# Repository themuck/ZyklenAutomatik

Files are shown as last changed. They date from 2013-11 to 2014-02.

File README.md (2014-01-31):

ZyklenAutomatik
==========
Elektronisches Getriebe mit Zyklen Funktion auf auf Arduino Mega2560 Basis. Zur Nachbildung eines Getriebes für die Leitspindel einer Drehbank

<br />Dieses Werk bzw. Inhalt ist lizenziert unter einer <a rel="license" href="http://creativecommons.org/licenses/by-nc-sa/3.0/deed.de">Creative Commons Namensnennung - Nicht-kommerziell - Weitergabe unter gleichen Bedingungen 3.0 Unported Lizenz</a>.

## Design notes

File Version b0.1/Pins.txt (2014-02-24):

Pins - Funktion RJ45 (Encoder A,A' / B, B' / Z,Z')
8- GND 	BR
7- 5V	BR/W
6- B+	GR
5- Z-	BL/w
4- Z+	BL
3- B-	GR/W
2- A- 	OR
1- A+	OR/W
---------------
Pins - Funktion RJ45 (Encoder A/B/Z und Eingänge (Endschalter) )
8- GND
7- 5V
6- B+
5- Arduino 41
4- Z+
3- Arduino 39
2- Arduino 38
1- A+
--------------
Pins - Funktion RJ45 (Endstufe)
8- GND
7- Arduino 11 (Status Eingang)
6- 5V
5- Arduino 8 Dir Pin
4- 5V
3- Arduino 9 Step Pin
2- GND
1- Arduino 10 Enable

----------------
S1- Arduino 42
S2- Arduino 43
S3- Arduino 44
S4- Arduino 45
S5- Arduino 46
S6- Arduino 47
S7- Arduino 48
S8- Arduino 49
S9- Arduino 50 
S10- Adruino 51
S11- Arduino 40 (Encoder Taster)
S12 - Reset

Encoder A- Arduino 19 Int4
Encoder B- Arduino 20 Int3

Externer Encoder A- Arduino 2 Int0
Externer Encoder B- Arduino 3 Int1

Endschalter - 38
Endschalter - 39
Endschalter - 41

LED Status 1- Arduino 53
LED Status 2- Arduino 52
LED Status 3- Arduino 30
LED Status 4- Arduino 31
Summer- Arduino 32

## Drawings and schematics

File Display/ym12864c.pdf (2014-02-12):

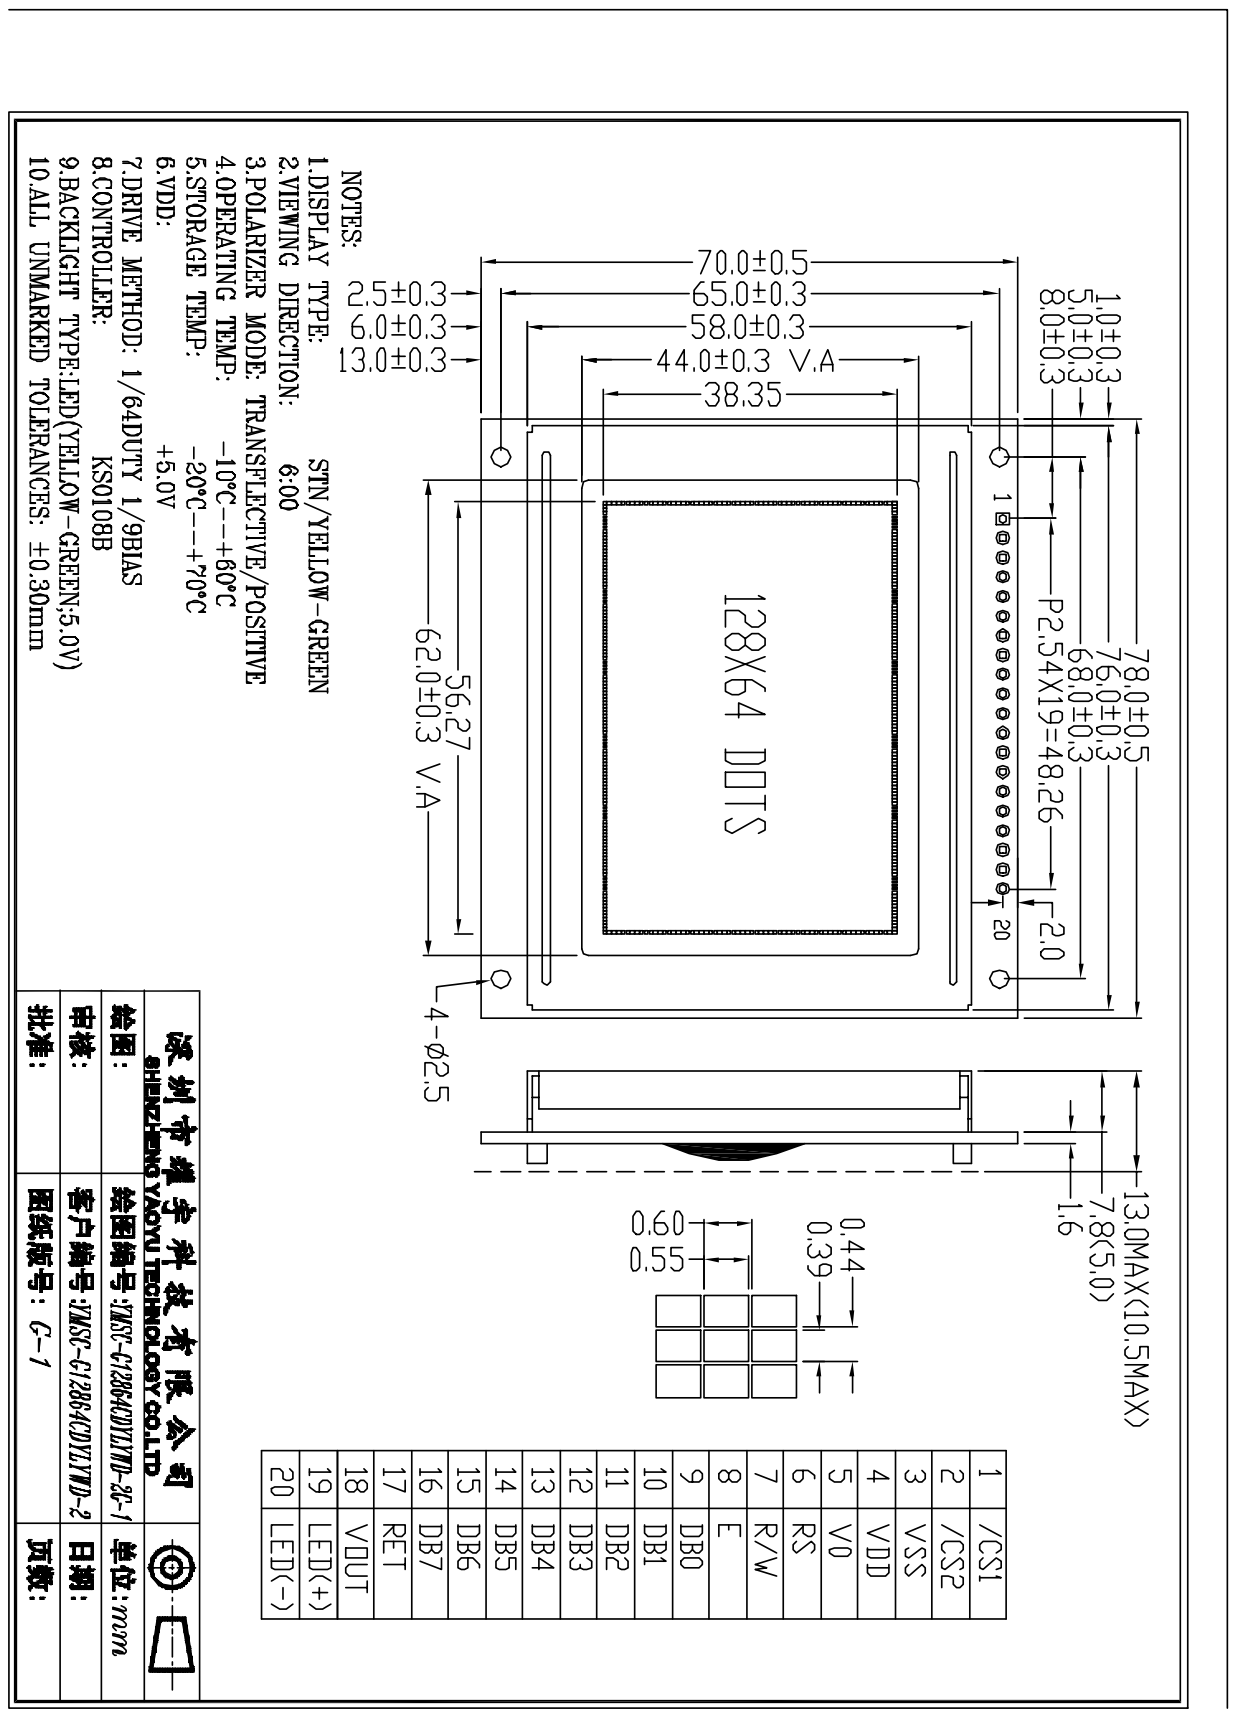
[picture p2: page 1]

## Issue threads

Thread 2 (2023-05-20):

Problem

beyma1, 2023-05-20:
Czy kod jest kompletny? Zbudowałem projekt, wgrałem soft do arduino ale nie ma żadnej reakcji na impulsator. Tak samo nie ma "tej kreseczki"? co przesuwa się gdy zmienia się tryb na wyświetlaczu. Co może być przyczyną?

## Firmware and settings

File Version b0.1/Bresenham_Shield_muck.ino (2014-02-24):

// use AVR446 - Linear speed control of stepper motor Documentation, Atmel AVR Application Note
// ZykloenAutomatik is Open Source under CC BY-NC-SA 3.0 
// https://github.com/themuck/ZyklenAutomatik

/* TO DO 
- Aufräumen
- Kommentare
- delay(); Funktion entfernen
- Shönere Struktur, If anweisungen - > switch / case 
- Programm Verriegelungen 
- Entprellroutine ?
- Winkel Positions Anzege
- Visualisierung LEDs, Töne 
- Variablen größe
- Bresenham rirchtung
- Zahlenwerte Negativ verriegeln 
-....
*/

#include <glcd.h>
#include "ZyklenAutomatik_Config.h"
#include <fonts/allFonts.h>
#include "EEPROMAnything.h"
#include <EEPROM.h>

long fehler = resolution/2; 

long spindle_posi = 0; //absolut 
int spindle_angle = 0; //Winkel
boolean spindle_dir;
unsigned int spindle_rpm = 0;

long uiInterruptCountHelp=0; // hilfsZÃƒÂ¤her fÃƒÂ¼r die rpm Messung
long spindel_puls_s=0; // ZÃƒÂ¤her fÃƒÂ¼r die rpm Messung 
long ulTimeHelp, ulMillisHelp;// Zeit speicher fÃƒÂ¼r die Messung

boolean spindle_Aold = 1;
boolean spindle_Bnew = 0;

long encoder_posi = 0;

boolean encoder_Aold = 1;
boolean encoder_Bnew = 0;

long stepper_rad_sec;
long stepper_posi = 0;
long stepper_steps_pr = 0 ; 
long stepper_posi_tmp = 0 ;
boolean x;
int temp;
char mode ;
char mode2 ;
char edit;
char menue ;
long steps_toaccel;

int timer1;

static unsigned int step_count = 0;
	// Holds next delay period.
unsigned int new_step_delay;
	// Remember the last step delay used when accelrating.
static int last_accel_delay;

void setup() {  
	io_init(); 
		
	attachInterrupt(3, doEncoderB, RISING );	 
	attachInterrupt(0, doSpindleA, CHANGE);
	attachInterrupt(1, doSpindleB, CHANGE);
        attachInterrupt(2, doSpindleZ, CHANGE);
  
	GLCD.Init();  	
	GLCD.SelectFont(SystemFont5x7);
	GLCD.CursorTo(3,2);
	GLCD.print("ZyklenAutomatik");
	GLCD.EraseTextLine();
		GLCD.CursorTo(3,5);
		GLCD.print("CC BY-NC-SA 3.0");
		GLCD.EraseTextLine();
	delay(2000);
	speed_cntr_Init_Timer1();
	
	
	if (!digitalRead(encoder)) // Lade Defalut werte und nicht den Speicher
	{	digitalWrite(led2,LOW);
		GLCD.CursorTo(0,3);
		GLCD.print("load default values");
		GLCD.EraseTextLine();
		while(!digitalRead(encoder));
		delay(1000);
		digitalWrite(led2,HIGH);
		write_default_config();
		
	}else EEPROM_readAnything(0, configuration);
  
	 print_menue();
	 print_edit_cursor();
	 //-------------------------- Draw Lines --------------------------------
	 GLCD.DrawHLine(0,50,127);
	 GLCD.DrawHLine(0,54,127);
	 GLCD.DrawVLine(3,0,49);
}
void loop(){
  //Check each changes in position
  
print_menue_numbers();

if ((!digitalRead(right) || !digitalRead(left)) && status.key_pressed == FALSE && status.running == FALSE&& mode == 0)
{	mode2 = 0; // Automatiken zurück setzen 
	if (!digitalRead(right))
	{
		menue++;
	}
	if (!digitalRead(left))
	{
		menue--;
	}
	if (menue >= 5)
	{menue = 0;
	}
	
	if (menue < 0)
	{menue = 4;
	}
	print_menue();		
	status.key_pressed = TRUE;
}

if ((!digitalRead(up) || !digitalRead(down)) && status.key_pressed == FALSE && status.running == FALSE )
{
	if (!digitalRead(down))
	{
		edit++;
	}
	if (!digitalRead(up))
	{
		edit--;
	}
	if (edit >= 5 )
	{edit = 0;
	}
	
	if ( edit < 0)
	{edit = 4;
	}	
	print_edit_cursor();
	status.key_pressed = TRUE;
}


  // daten speichern ---------------------------------
  if (!digitalRead(encoder) && menue == 4 && edit == 4 && status.key_pressed == FALSE) {
	  digitalWrite(led2, LOW);
	  EEPROM_writeAnything(0, configuration);
	  status.key_pressed = TRUE;delay(1000);
	  digitalWrite(led2, HIGH);}	
	  
  // nummern auf 0 setzen------------------------------  
  if (!digitalRead(encoder) && status.key_pressed == FALSE) {write_edit_number(0);status.key_pressed = TRUE;}
  // Mode Wechsel-------------------------------------- 
  if (!digitalRead(S5)&& status.key_pressed == FALSE&& status.running == FALSE ) {mode = 0; print_menue();digitalWrite(led1, HIGH);status.key_pressed = TRUE;}
  if (!digitalRead(S6)&& menue != 4&& status.key_pressed == FALSE&& status.running == FALSE ) {mode = 1; print_menue();digitalWrite(led1, LOW);status.key_pressed = TRUE;}
	  
	  
  if (status.running == TRUE) {digitalWrite(led4, LOW);}
	  else digitalWrite(led4, HIGH);
  
    // *****************************************************Programm Funktionen--------------------------------------------------------------------------  
	
  if (mode == 0 && menue != 4){
	  if (status.running == FALSE &&!digitalRead (S1)) {speed_cntr_Move(100,configuration.slow_move);}
	  if (status.running == FALSE &&!digitalRead (S2)) {speed_cntr_Move(-100,configuration.slow_move);}
	  if (status.running == FALSE &&!digitalRead (S3)) {speed_cntr_Move(1000,configuration.fast_move);}
	  if (status.running == FALSE &&!digitalRead (S4)) {speed_cntr_Move(-1000,configuration.fast_move);}
		}
    
   // Gewinde --------------------------------------------------------
	if (mode == 1 && menue == 0){
			if (status.running == TRUE && (!digitalRead (S2) || !digitalRead (S3))&& status.key_pressed == FALSE) {decl_trigger();;status.key_pressed = TRUE; status.goback_trigger = FALSE;}

			if (status.running == FALSE && !digitalRead (S4)&& status.key_pressed == FALSE && (stepper_posi_tmp-stepper_posi)!= stepper_posi) {speed_cntr_Move((stepper_posi_tmp-stepper_posi),configuration.fast_move);status.goback_trigger = FALSE;status.key_pressed = TRUE;}	
				
			if (status.running == FALSE && !digitalRead (S1)&& status.key_pressed == FALSE && status.thread == FALSE) {status.thread = TRUE; status.goback_trigger = TRUE;status.key_pressed = TRUE;stepper_posi_tmp = stepper_posi; speed_cntr_Move(configuration.thread_length,stepper_rad_sec);}	
		    //  Auto---------------		
		    if (status.running == FALSE && stepper_posi == (stepper_posi_tmp+configuration.thread_length) && status.goback_trigger == TRUE && mode2 == 1){delay(configuration.delay_move);speed_cntr_Move((stepper_posi_tmp-stepper_posi),configuration.fast_move); status.thread = FALSE; status.goback_trigger = FALSE;}
			
			// Toogle Auto---------------
			if (!digitalRead (left)&& status.key_pressed == FALSE&& status.running == FALSE ) {mode2 = 0; print_menue();status.key_pressed = TRUE;status.thread = FALSE; status.goback_trigger = FALSE;}
			if (!digitalRead (right)&& status.key_pressed == FALSE&& status.running == FALSE ) {mode2 = 1; print_menue();status.key_pressed = TRUE;status.thread = FALSE; status.goback_trigger = FALSE;}
										
		}
		
		// Schleifen --------------------------------------
		if (mode == 1 && menue == 1){
			if (status.running == TRUE && (!digitalRead (S2) || !digitalRead (S3))&& status.key_pressed == FALSE) {decl_trigger();;status.key_pressed = TRUE; status.goback_trigger = FALSE;}

			if (status.running == FALSE &&!digitalRead (S4)&& status.key_pressed == FALSE && (stepper_posi_tmp-stepper_posi)!= stepper_posi) {speed_cntr_Move((stepper_posi_tmp-stepper_posi),configuration.fast_move);status.goback_trigger = FALSE;status.key_pressed = TRUE;}
			
			if (status.running == FALSE && !digitalRead (S1)&& status.key_pressed == FALSE && status.goback_trigger == FALSE) {status.goback_trigger = TRUE;status.key_pressed = TRUE;stepper_posi_tmp = stepper_posi; speed_cntr_Move(configuration.grind_way,configuration.grind_speed);status.dir = FALSE;}
			//  Auto---------------
			if(mode2 == 1 && status.goback_trigger == TRUE && status.running == FALSE ){ 
			if (status.dir == FALSE && status.running == FALSE ) {delay(configuration.delay_move);speed_cntr_Move(-configuration.grind_way,configuration.grind_speed);status.dir = TRUE;}
			if (status.dir == TRUE && status.running == FALSE ) {delay(configuration.delay_move);speed_cntr_Move(configuration.grind_way,configuration.grind_speed);status.dir = FALSE;}
			}
			
			// Toogle Auto---------------
			if (!digitalRead (left)&& status.key_pressed == FALSE&& status.running == FALSE ) {mode2 = 0; print_menue();status.key_pressed = TRUE; status.goback_trigger = FALSE;}
			if (!digitalRead (right)&& status.key_pressed == FALSE&& status.running == FALSE ) {mode2 = 1; print_menue();status.key_pressed = TRUE; status.goback_trigger = FALSE;}
						
			}
			
			
		// Drehen -----------------------------------------	
		if (mode == 1 && menue == 2){ 
			
			if (status.running == TRUE && (!digitalRead (S2) || !digitalRead (S3))&& status.key_pressed == FALSE) {decl_trigger();;status.key_pressed = TRUE;}
				
			if (status.running == FALSE &&!digitalRead (S1)&& status.key_pressed == FALSE) {speed_cntr_Move(configuration.cutting_way,configuration.cutting_speed);status.key_pressed = TRUE;}
			if (status.running == FALSE &&!digitalRead (S4)&& status.key_pressed == FALSE) {speed_cntr_Move(-configuration.cutting_way,configuration.cutting_speed);status.key_pressed = TRUE;}
										
		}

		// Bewegen ----------------------------------------
		if (mode == 1 && menue == 3){
			
				  if (status.running == FALSE &&!digitalRead (S1)&& status.key_pressed == FALSE) {speed_cntr_Move(configuration.move_way,configuration.move_slow_speed);status.key_pressed = TRUE;}
				  if (status.running == FALSE &&!digitalRead (S2)&& status.key_pressed == FALSE) {speed_cntr_Move(-configuration.move_way,configuration.move_slow_speed);status.key_pressed = TRUE;}
				  if (status.running == FALSE &&!digitalRead (S3)&& status.key_pressed == FALSE) {speed_cntr_Move(configuration.move_way,configuration.move_fast_speed);status.key_pressed = TRUE;}
				  if (status.running == FALSE &&!digitalRead (S4)&& status.key_pressed == FALSE) {speed_cntr_Move(-configuration.move_way,configuration.move_fast_speed);status.key_pressed = TRUE;}
		}
		
		
		

   
    ulMillisHelp = millis();
    if(ulTimeHelp <= ulMillisHelp )
    {   		
		spindel_puls_s  = uiInterruptCountHelp;
		uiInterruptCountHelp=0;
		ulTimeHelp = (ulMillisHelp + 1000);
		   
		   spindle_rpm =  (spindel_puls_s*60)/(resolution) ;
          if(status.running == FALSE){
		   stepper_steps_pr = ((long)configuration.thread_pitch * steps_mm)/100;
		   stepper_rad_sec = ((long)2*spindle_rpm*pi*stepper_steps_pr)/((long)FSPR*60);
		   steps_toaccel = (long)stepper_rad_sec*stepper_rad_sec/(long)(((long)A_x20000*accel_stepper)/100);
		   }
					       
    }	
	  
	  
    
    if(!(!digitalRead(encoder)||!digitalRead(S1)||!digitalRead(S2)||!digitalRead(S3)||!digitalRead(S4)||!digitalRead(S5)||!digitalRead(S6)||!digitalRead(left)||!digitalRead(right)||!digitalRead(up)||!digitalRead(down)||!digitalRead(encoder))) {status.key_pressed = FALSE;}
;
 
}

/*
Menue = 

0 Gewinde
1 Schleifen
2 Drehen 
3 Bewegen
4 Optionen 

*/

void print_menue ()
{
	
	GLCD.FillRect(0,52,127,1,WHITE);
	switch (menue){
		case 0:
		GLCD.CursorTo(6,0);
		GLCD.print("Gewinde"); 
		GLCD.EraseTextLine();
		GLCD.CursorTo(1,1);
		GLCD.print("RPM:");
		GLCD.EraseTextLine();
		
		GLCD.CursorTo(1,3);
		GLCD.print("Besch. Weg:");
		GLCD.EraseTextLine();		
		
		GLCD.CursorTo(1,2);
		GLCD.print("Position:");
		GLCD.EraseTextLine();
		GLCD.CursorTo(1,4);
		GLCD.print("Gew. Laenge:");
		GLCD.EraseTextLine();
		GLCD.CursorTo(1,5);
		GLCD.print("Steigung P:");
		
		GLCD.EraseTextLine();
		GLCD.FillRect(1,52,24,0);
		
		if(mode==0){
		GLCD.CursorTo(0,7);
		GLCD.print("  <     >   <<    >> ");
		GLCD.EraseTextLine();
		}else
		{
			GLCD.CursorTo(0,7);
			GLCD.print("  GO  |  Stop  | Ret.");
			GLCD.EraseTextLine();
			
			if(mode2==0){
				GLCD.CursorTo(1,0);
				GLCD.print("<    Ret. manual   >");
				GLCD.EraseTextLine();
			}else
			{
				GLCD.CursorTo(1,0);
				GLCD.print("<    Ret. auto     >");
				GLCD.EraseTextLine();
			}
			
		}
		
		
		
		break;
		
		case 1:
		GLCD.CursorTo(6,0);
		GLCD.print("Schleifen");
		GLCD.EraseTextLine();
		GLCD.CursorTo(1,1);
		GLCD.print("RPM:");
		GLCD.EraseTextLine();
		GLCD.CursorTo(1,2);
		GLCD.print("Position:");
		GLCD.EraseTextLine();
		GLCD.CursorTo(1,3);
		GLCD.EraseTextLine();
		GLCD.CursorTo(1,4);
		GLCD.print("Weg:");
		GLCD.EraseTextLine();
		GLCD.CursorTo(1,5);
		GLCD.print("Geschw:");
		GLCD.EraseTextLine();
		
		GLCD.FillRect(26,52,24,0);
		if(mode==0){
			GLCD.CursorTo(0,7);
			GLCD.print("  <     >   <<    >> ");
			GLCD.EraseTextLine();
			GLCD.CursorTo(1,3);
			GLCD.EraseTextLine();
		}else
		{
			GLCD.CursorTo(0,7);
			GLCD.print("  GO  |  Stop  | Ret.");
			GLCD.EraseTextLine();
			
			if(mode2==0){
				GLCD.CursorTo(1,0);
				GLCD.print("<    Ret. manual   >");
				GLCD.EraseTextLine();
			}else
			{
				GLCD.CursorTo(1,0);
				GLCD.print("<       Auto       >");
				GLCD.EraseTextLine();
			}
			
		}
		break;
		
		case 2:
		GLCD.CursorTo(6,0);
		GLCD.print("Drehen");
		GLCD.EraseTextLine();
		GLCD.CursorTo(1,1);
		GLCD.print("RPM:");
		GLCD.EraseTextLine();
		GLCD.CursorTo(1,2);
		GLCD.print("Position:");
		GLCD.EraseTextLine();
		GLCD.CursorTo(1,3);
		GLCD.EraseTextLine();
		GLCD.CursorTo(1,4);
		GLCD.print("Weg:");
		GLCD.EraseTextLine();
		GLCD.CursorTo(1,5);
		GLCD.print("Geschw:");
		
		GLCD.EraseTextLine();
		GLCD.FillRect(51,52,24,0);
		if(mode==0){
			GLCD.CursorTo(0,7);
			GLCD.print("  <     >   <<    >> ");
			GLCD.EraseTextLine();
		}else
		{
			GLCD.CursorTo(0,7);
			GLCD.print("< GO  |  Stop  | GO >");
			GLCD.EraseTextLine();
		}
		break;
		
		case 3:
		GLCD.CursorTo(6,0);
		GLCD.print("Bewegen");
		GLCD.EraseTextLine();
		GLCD.CursorTo(1,1);
		GLCD.print("RPM:");
		GLCD.EraseTextLine();
		GLCD.CursorTo(1,3);
		GLCD.print("Weg:");
		GLCD.EraseTextLine();
		GLCD.CursorTo(1,2);
		GLCD.print("Position:");
		GLCD.EraseTextLine();
		GLCD.CursorTo(1,4);
		GLCD.print("Eil G.:");
		GLCD.EraseTextLine();
		GLCD.CursorTo(1,5);
		GLCD.print("Arb G.:");
		
		GLCD.EraseTextLine();
		GLCD.FillRect(76,52,24,0);
			if(mode==0){
				GLCD.CursorTo(0,7);
				GLCD.print("  <     >   <<    >> ");
				GLCD.EraseTextLine();
			}else
			{
				GLCD.CursorTo(0,7);
				GLCD.print("  <     >   <<    >> ");
				GLCD.EraseTextLine();
			}
		break;
		
		case 4:
		GLCD.CursorTo(6,0);
		GLCD.print("Optionen"); // fixed, danke Jürgen
		GLCD.EraseTextLine();
		GLCD.CursorTo(1,1);
		GLCD.print("Verz.:");
		GLCD.EraseTextLine();
		GLCD.CursorTo(1,2);
		GLCD.print("Eil G.:");
		GLCD.EraseTextLine();
		GLCD.CursorTo(1,3);
		GLCD.print("Arb G.:");
		GLCD.EraseTextLine();
		GLCD.CursorTo(1,4);
		GLCD.print("Spiel:");
		GLCD.EraseTextLine();
		GLCD.CursorTo(1,5);
		GLCD.print("Speichern?");
		
		GLCD.EraseTextLine();
		GLCD.FillRect(101,52,24,0);
		GLCD.CursorTo(0,7);
		GLCD.EraseTextLine();
		break;


	}
	
} 


void print_edit_cursor ()
{
	
	GLCD.FillRect(0,0,2,49,WHITE);
	switch (edit){
		case 0:
		
		GLCD.FillRect(1,8,0,6);
		break;
		
		case 1:
		
		GLCD.FillRect(1,16,0,6);
		break;
		
		case 2:		
		
		GLCD.FillRect(1,24,0,6);
		break;
		
		case 3:
		
		GLCD.FillRect(1,32,0,6);
		break;
		
		case 4:
		
		GLCD.FillRect(1,40,0,6);
		break;


	}
	
}

void print_menue_numbers ()
{
	  switch (menue){
		  case 0: // Gewinde ---------------------------
		  if (status.running == FALSE){
			 GLCD.CursorTo(14,1);
			GLCD.PrintNumber(spindle_angle);
			GLCD.EraseTextLine();
			  
			GLCD.CursorTo(14,3);
			GLCD.print((float)steps_toaccel/steps_mm);
			GLCD.EraseTextLine();
				  
			  
						  
			  GLCD.CursorTo(14,4);
			  GLCD.print((float)configuration.thread_length/steps_mm);
			  GLCD.EraseTextLine();
			  GLCD.CursorTo(14,5);
			  GLCD.print(((float)configuration.thread_pitch/100));
			  GLCD.EraseTextLine();
			  }
			  GLCD.CursorTo(14,2);
			  GLCD.print((float)stepper_posi/steps_mm);
			  GLCD.EraseTextLine();
		  
		  break;
		  
		    case 1:// Schleifen ---------------------------
		    if (status.running == FALSE){
			    
			 GLCD.CursorTo(14,1);
			 GLCD.PrintNumber(spindle_rpm);
			 GLCD.EraseTextLine();
			
			 GLCD.CursorTo(14,4);
			 GLCD.print((float)configuration.grind_way/steps_mm);
			 GLCD.EraseTextLine();
			 GLCD.CursorTo(14,5);
			 GLCD.print((float)((long)configuration.grind_speed*FSPR)/((long)2*pi*steps_mm) );
		     GLCD.EraseTextLine();
			 }
			  GLCD.CursorTo(14,2);
			  GLCD.print((float)stepper_posi/steps_mm);
			  GLCD.EraseTextLine();
		     
		    break;
			
			    case 2:
			    if (status.running == FALSE){
				    
				    GLCD.CursorTo(14,1);
				    GLCD.PrintNumber(spindle_rpm);
				    GLCD.EraseTextLine();
				    
				    GLCD.CursorTo(14,4);
				    GLCD.print((float)configuration.cutting_way/steps_mm);
				    GLCD.EraseTextLine();
				    GLCD.CursorTo(14,5);
				    GLCD.print((float)((long)configuration.cutting_speed*FSPR)/((long)2*pi*steps_mm) );
				    GLCD.EraseTextLine();
			    }
				GLCD.CursorTo(14,2);
				GLCD.print((float)stepper_posi/steps_mm);
				GLCD.EraseTextLine();
			    
			    break;
				
				    case 3:
				    if (status.running == FALSE){
					    
					    GLCD.CursorTo(14,1);
					    GLCD.PrintNumber(spindle_rpm);
					    GLCD.EraseTextLine();
					   
						GLCD.CursorTo(14,3);
						GLCD.print((float)configuration.move_way/steps_mm);
						GLCD.EraseTextLine();
					    GLCD.CursorTo(14,4);
					    GLCD.print((float)((long)configuration.move_fast_speed*FSPR)/((long)2*pi*steps_mm) );
					    GLCD.EraseTextLine();
					    GLCD.CursorTo(14,5);
					    GLCD.print((float)((long)configuration.move_slow_speed*FSPR)/((long)2*pi*steps_mm) );
					    GLCD.EraseTextLine();
				    }
					 GLCD.CursorTo(14,2);
					 GLCD.print((float)stepper_posi/steps_mm);
					 GLCD.EraseTextLine();
				    
				    break;
					
					  case 4:
					  if (status.running == FALSE){
						  
						  GLCD.CursorTo(14,1);
						  GLCD.print((float)configuration.delay_move/1000);
						  GLCD.EraseTextLine();  
						  GLCD.CursorTo(14,4);
						  GLCD.print(configuration.backlash_move);
						  GLCD.EraseTextLine();
						  GLCD.CursorTo(14,2);
						  GLCD.print((float)((long)configuration.fast_move*FSPR)/((long)2*pi*steps_mm) );
						  GLCD.EraseTextLine();
						  GLCD.CursorTo(14,3);
						  GLCD.print((float)((long)configuration.slow_move*FSPR)/((long)2*pi*steps_mm) );
						  GLCD.EraseTextLine();
					  }
					  
					  
					  break;

	  }
	 	
}

void doEncoderB(){
	
 if (digitalRead(encoder_PinA) == digitalRead(encoder_PinB)) {
	 encoder_posi--;
	 trigger_edit_number(-1);
	 } 
	 
	 else {
	 encoder_posi++;
	 trigger_edit_number(+1);
 }
}
// Interrupt on A changing state
void doSpindleA(){
  spindle_Bnew^spindle_Aold ? spindle_posi++:spindle_posi--;
  spindle_Bnew^spindle_Aold ? spindle_angle++:spindle_angle--;
  spindle_Bnew^spindle_Aold ? spindle_dir = CW :spindle_dir = CCW ;
  uiInterruptCountHelp++;
  
  // winkelpositionen !! 0 und resolution liegen auf einem punkt, 0 = resolution!!
  if (spindle_angle >= resolution  ){spindle_angle = 0; }
  if (spindle_angle < 0){spindle_angle = resolution-1 ;}

 // Einkoppeln der Spindel
 if (digitalRead (spindle_PinZ) && status.thread == TRUE && status.backlash == FALSE)
 {	 srd.run_state = ACCEL;
	 srd.accel_count = 0;
	 
	 status.running = TRUE;
	 OCR1A = 10;
	 // Set Timer/Counter to divide clock by 8
	 TCCR1B |= ((0<<CS12)|(1<<CS11)|(0<<CS10));
 }	
	
 if (srd.run_state == AUTO)
 {
 
	 fehler = fehler-stepper_steps_pr;
	 if (fehler < 0 )
	 { sm_driver_StepOutput();
		 step_count++;
		 fehler = fehler + resolution;
	 }
	 new_step_delay = srd.min_delay;
		if(step_count >= srd.decel_start) // Abbruch bedingung
		{	decl_trigger();
		}
 }
  spindle_Aold=digitalRead(spindle_PinA); 
   
  
}
// Interrupt on B changing state
void doSpindleB(){
  spindle_Bnew=digitalRead(spindle_PinB);

  spindle_Bnew^spindle_Aold ? spindle_posi++:spindle_posi--;
  spindle_Bnew^spindle_Aold ? spindle_angle++:spindle_angle--;
  spindle_Bnew^spindle_Aold ? spindle_dir = CW :spindle_dir = CCW ;
  uiInterruptCountHelp++;
  // winkelpositionen !! 0 und resolution liegen auf einem punkt, 0 = resolution!!
  if (spindle_angle >= resolution  ){spindle_angle = 0; }
  if (spindle_angle < 0){spindle_angle = resolution-1 ;}
	  
// Einkoppeln der Spindel 
	 if (digitalRead (spindle_PinZ) && status.thread == TRUE && status.backlash == FALSE)
	 {	 srd.run_state = ACCEL;
		 srd.accel_count = 0;
		 
		 status.running = TRUE;
		 OCR1A = 10;
		 // Set Timer/Counter to divide clock by 8
		 TCCR1B |= ((0<<CS12)|(1<<CS11)|(0<<CS10));
	 }
	

 if (srd.run_state == AUTO)
 {
	 
	 fehler = fehler-stepper_steps_pr;
	 if (fehler < 0 )
	 { sm_driver_StepOutput();
		 step_count++;
		 fehler = fehler + resolution;
	 }
	 
	 new_step_delay = srd.min_delay;
	 if(step_count >= srd.decel_start) // Abbruch bedingung 
	 {	  new_step_delay = srd.min_delay;
		 
		if(step_count >= srd.decel_start)
		{	
			decl_trigger();
		}
	 }
 }
  

}

void sm_driver_StepOutput()
{
	
	if (srd.dir == CW){
		digitalWrite(dirpin, HIGH);   // sets the LED on
		digitalWrite(steppin, LOW);   // sets the LED on
		if(srd.run_state != BACKLASH) stepper_posi++;
	}
	else{
		if(srd.run_state != BACKLASH) stepper_posi--;
		digitalWrite(dirpin, LOW);   // sets the LED on
		digitalWrite(steppin, LOW);   // sets the LED on
	}
   delayMicroseconds(stepper_delay);
   digitalWrite(steppin, HIGH);   // sets the LED on

}
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

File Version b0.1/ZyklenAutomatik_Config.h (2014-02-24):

// include the library header
#include <glcd.h>
#include <fonts/allFonts.h>
#include <avr/io.h>
#include <avr/interrupt.h>

#define encoder_PinA 19
#define encoder_PinB 20

#define spindle_PinA 2
#define spindle_PinB 3
#define spindle_PinZ 21 //int0

#define S1  42
#define S2  43
#define S3  44
#define S4  45
#define S5  46
#define S6  47
#define up  51
#define down  49
#define right  50
#define left  48
#define encoder  40

#define led2  53
#define led1  52
#define led3  30
#define led4  31
#define out3  8

#define dirpin 10 //pin fÃ¼r Richtung
#define steppin  9 //pin fÃ¼r Schritt



#define tweeter  32
 
#define resolution 1600  //Resolution Encoder

#define stepper_delay 3

#define backlash_speed (A_T_x100/700) 
#define FSPR 400
#define steps_mm 200 // aus der Rechnungstabelle

#define pi  314

// Speed ramp Data aus der Berechnungstabelle
#define A_T_x100 1570796
#define T1_FREQ_148 13520
#define A_SQ 157079632
#define A_x20000 157

#define accel_stepper 50000 

#define default_thread_pitch 225 // Steigung 2mm entspricht 200, 1.06 entspricht 106... !!
#define default_thread_length 0
#define default_grind_way 0
#define default_grind_speed 0
#define default_cutting_way 0
#define default_cutting_speed 0
#define default_move_way 200
#define default_move_fast_speed 6000
#define default_move_slow_speed 1000
#define default_fast_move 6000
#define default_slow_move 1000
#define default_delay_move 2
#define default_backlash_move 112 // Schritte zur kompensation

// Speed ramp states
#define STOP  0
#define ACCEL 1
#define DECEL 2
#define RUN   3
#define AUTO  4
#define BACKLASH 5

#define CW  0
#define CCW 1
#define TRUE 1
#define FALSE 0


typedef struct {
	//! What part of the speed ramp we are in.
	unsigned char run_state : 3;
	//! Direction stepper motor should move.
	unsigned char dir : 1;
	
	unsigned char dir_old : 1;
	//! Peroid of next timer delay. At start this value set the accelration rate.
	unsigned int step_delay;
	//! What step_pos to start decelaration
	unsigned int decel_start;
	//! Sets deceleration rate.
	signed int decel_val;
	//! Minimum time delay (max speed)
	signed int min_delay;
	//! Counter used when accelerateing/decelerateing to calculate step_delay.
	signed int accel_count;
} speedRampData;

speedRampData srd;

struct GLOBAL_FLAGS {
	//! True when stepper motor is running.
	unsigned char running:1;
	//! True when uart has received a string (ended with '/r').
	unsigned char cmd:1;
	//! Dummy bits to fill up a byte.
	
	unsigned char thread:1;	
	
	unsigned char encoder_trigger:1;
	
	unsigned char backlash_trigger:1;
	
	unsigned char backlash:1;
	
	unsigned char key_pressed:1;
	
	unsigned char goback_trigger:1;
	
	unsigned char dir:1;
	
};

struct GLOBAL_FLAGS status = {FALSE, FALSE, FALSE, FALSE,FALSE,FALSE};
	
	struct config_t{
		long thread_pitch ; // Steigung 2mm entspricht 200, 1.06 entspricht 106... !!
		long thread_length ;
		long grind_way;
		long grind_speed ;
		long cutting_way ;
		long cutting_speed;
		long move_way ;
		long move_fast_speed ;
		long move_slow_speed ;
		long fast_move ;
		long slow_move ;
		long delay_move ;
		long backlash_move;
	}configuration;

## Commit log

2013-11-18 Add PCB Files
    Eine SVG mit den Dimensionen und eine rohes Projekt für Target 3001
2013-11-18 PCB geändert
2013-11-20 1st gerber test
    [Zyklenautomatik_PCB_Mega2560_Pins_shield_muck.GBL, Zyklenautomatik_PCB_Mega2560_Pins_shield_muck.GBO, Zyklenautomatik_PCB_Mega2560_Pins_shield_muck.GBS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]
2013-11-21 Edit PCB
    [Zyklenautomatik_PCB_Mega2560_Pins_shield_muck.GBL, Zyklenautomatik_PCB_Mega2560_Pins_shield_muck.GBO, Zyklenautomatik_PCB_Mega2560_Pins_shield_muck.GBS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]
2014-01-24 edit test Sketch
    [Zyklenautomatik_PCB_Mega2560_Pins_shield_muck.XLS, Zyklenautomatik_PCB_Mega2560_Pins_shield_muck.ods, Zyklenautomatik_PCB_Mega2560_Pins_shield_muck_XLS.xls]
2014-01-27 add avr446
    [avr446.ods]
2014-01-28 PCB Change & Add DXF b0.1
    [Zyklenautomatik_PCB_Mega2560_Pins_shield_muck_b0.1.DXF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]
2014-01-30 edit software
    [Zyklenautomatik_PCB_Mega2560_Pins_shield_muck_b0.1.DXF]
2014-01-31 edit PCB b0.2
    [Zyklenautomatik_PCB_Mega2560_Pins_shield_muck_b0.2.GBL, Zyklenautomatik_PCB_Mega2560_Pins_shield_muck_b0.2.GBO, Zyklenautomatik_PCB_Mega2560_Pins_shield_muck_b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]
2014-02-12 upadte B2.02
    [Zyklenautomatik_PCB_Mega2560_Pins_shield_muck_b0.2.csv, Zyklenautomatik_PCB_Mega2560_Pins_shield_muck_b2.01.xls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]
2014-02-27 Aufgeräumt
    [Zyklenautomatik_PCB_Mega2560_Pins_shield_muck.ods, Zyklenautomatik_PCB_Mega2560_Pins_shield_muck_XLS.xls, Zyklenautomatik_PCB_Mega2560_Pins_shield_muck_b0.1.DX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]
